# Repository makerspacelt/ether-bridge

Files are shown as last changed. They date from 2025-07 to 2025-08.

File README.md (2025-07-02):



---
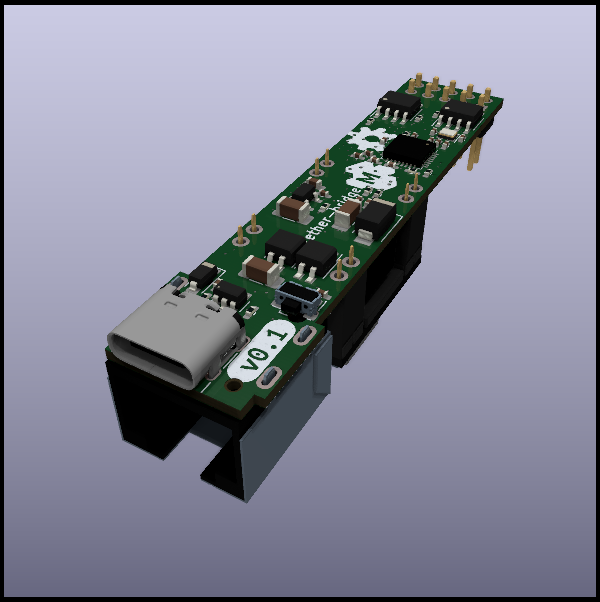
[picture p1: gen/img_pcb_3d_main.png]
PCB 3d main


Ether-bridge

NOTE: This is only a prototype now, so things might not work, and everything might change 

This hardware is meant as an Ethernet upgrade for devices that only support
I2C/UART/RS485/CAN communications. This should be used with a device-specific
firmware that exposes SCPI commands for all functions of a particular device.

Basic target features:

* Ethernet connection
* PoE .af 12w
* CAN
* RS-485
* i2c/UART
* 1x GPIO
* LXI/SCPI support via raw TCP
* Compatibility with ESPHome and Home Assistant

Dev NOTE: before commit, run `./kibot.sh` to regenerate documentation, bom, gerbers and other assets.

* [schematics.pdf](gen/schematics.pdf)
* [pcb.pdf with dimensions](gen/pcb.pdf)
* [ibom.html](gen/single/ibom.html)

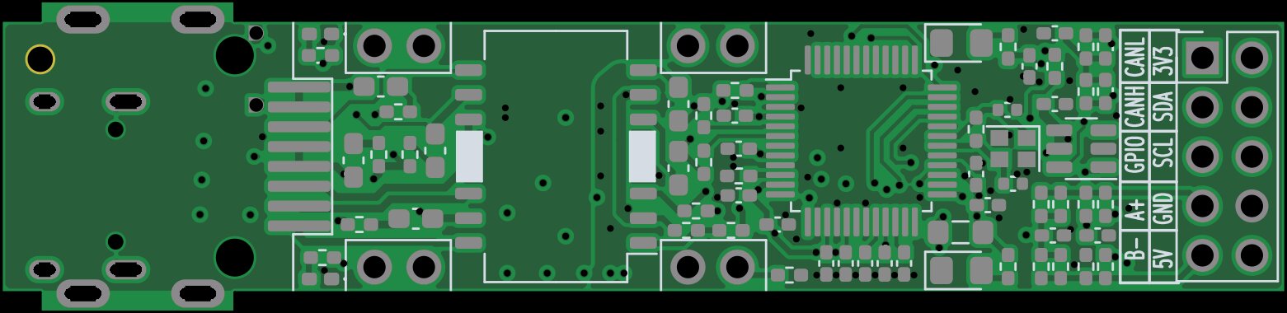
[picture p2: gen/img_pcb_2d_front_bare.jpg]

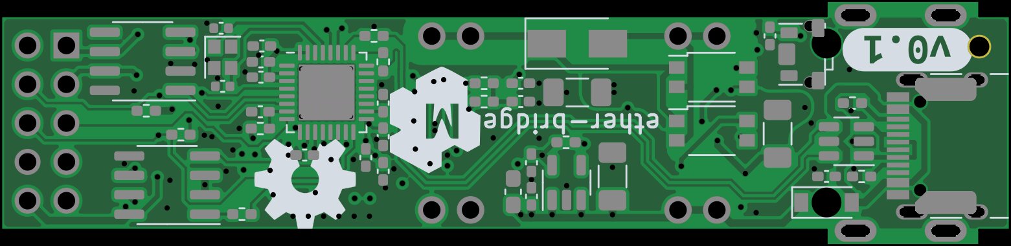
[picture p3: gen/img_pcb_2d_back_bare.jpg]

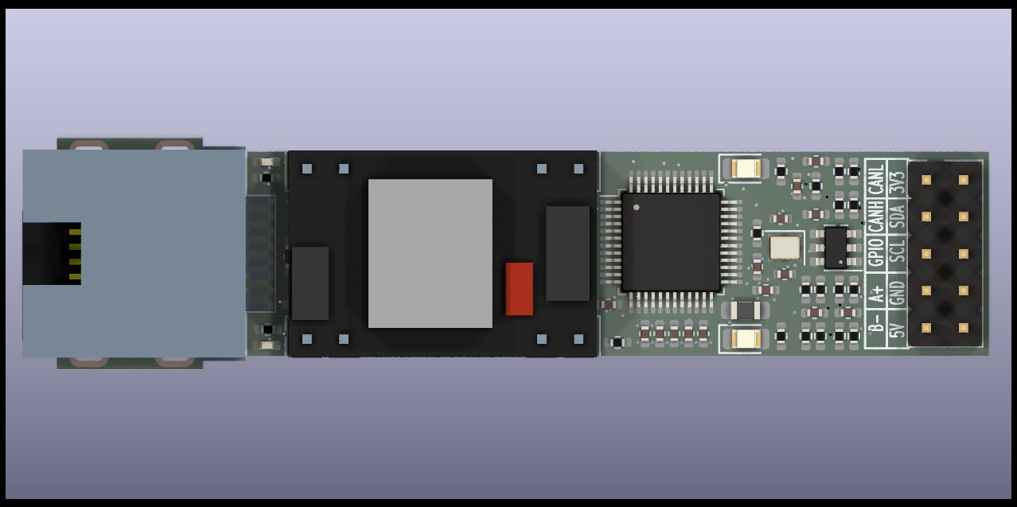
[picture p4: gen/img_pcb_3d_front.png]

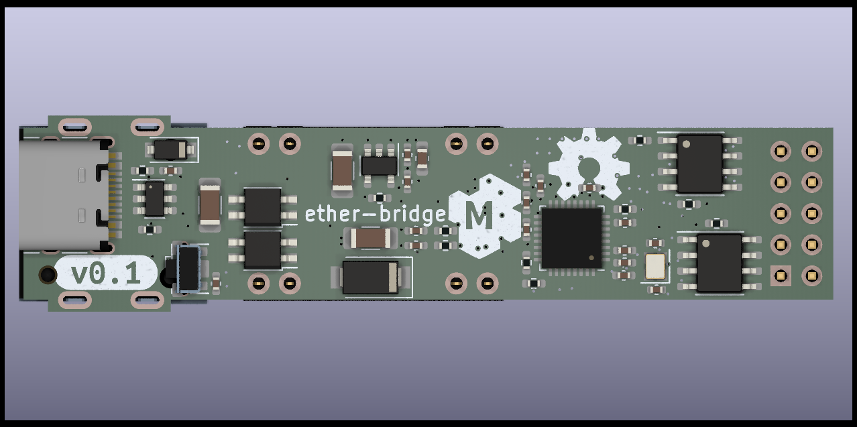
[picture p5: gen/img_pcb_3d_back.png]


---

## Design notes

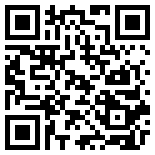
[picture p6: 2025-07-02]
gen/qr_link.png

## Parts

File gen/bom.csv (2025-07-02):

Row | Description | Part | References | Value | Footprint | Quantity Per PCB | Status | Datasheet | jlc-part-type | lcsc#
1 | Unpolarized capacitor | C | C31,C32,C33,C34 | 10p | C_0402_1005Metric | 4 |  | ~ | ??? | C1634
2 | Unpolarized capacitor | C | C17,C18 | 6n8 | C_0603_1608Metric_Pad1.08x0.95mm_HandSolder | 2 |  | ~ | B+ | C1631
3 | Unpolarized capacitor | C | C1,C2,C3,C4,C5,C8,C16,C19,C21,C22,C23,C25,C26,C27,C28,C29,C35,C36,C37,C41,C42,C43,C44,C45 | 100n | C_0402_1005Metric_Pad0.74x0.62mm_HandSolder | 24 |  | ~ | B+ | C1525
4 | Unpolarized capacitor | C | C40 | 1u | C_0402_1005Metric_Pad0.74x0.62mm_HandSolder | 1 |  | ~ | B+ | C52923
5 | Unpolarized capacitor | C | C24 | 4u7 | C_0402_1005Metric_Pad0.74x0.62mm_HandSolder | 1 |  | ~ | B+ | C23733
6 | Unpolarized capacitor | C | C6 | 100u/10v | C_1206_3216Metric_Pad1.33x1.80mm_HandSolder | 1 |  | ~ | E+ | C312983
7 | Unpolarized capacitor | C | C7 | 10u/10v | C_0603_1608Metric_Pad1.08x0.95mm_HandSolder | 1 |  | ~ | B+ | C19702
8 | Unpolarized capacitor | C | C9,C20,C30,C38,C39 | 10u/6v3 | C_0402_1005Metric_Pad0.74x0.62mm_HandSolder | 5 |  | ~ | B+ | C15525
9 | Unpolarized capacitor | C | C13 | 1n/2kv | C_1206_3216Metric_Pad1.33x1.80mm_HandSolder | 1 |  | ~ | B+ | C9196
10 | Unpolarized capacitor | C | C10,C11,C12,C15 | 22n/100v | C_0603_1608Metric_Pad1.08x0.95mm_HandSolder | 4 |  | ~ | E+ | C22374871
11 | Unpolarized capacitor | C | C14 | 4n7/2kv | C_1206_3216Metric_Pad1.33x1.80mm_HandSolder | 1 |  | ~ | E+ | C41017
12 | Schottky diode | D_Schottky | D8 | B5819W | D_SOD-123 | 1 |  | https://www.lcsc.com/datasheet/lcsc_datasheet_2304140030_Jiangsu-Changjing-Electronics-Technology-Co---Ltd--B5819W-SL_C8598.pdf | B+ | C8598
13 | Diode bridge, +ve/-ve/AC/AC | D_Bridge_+-AA | D3,D4 | D_Bridge_+-AA | Diode_Bridge_Diotec_MicroDil_3.0x3.0x1.8mm | 2 |  | https://lcsc.com/datasheet/lcsc_datasheet_2410122110_-DIOTEC-MYS250_C3589227.pdf | E+ | C3589227
14 | Light emitting diode | LED | D1,D2 | GREEN | LED_0805_2012Metric_Pad1.15x1.40mm_HandSolder | 2 |  | https://lcsc.com/datasheet/lcsc_datasheet_1806151820_Hubei-KENTO-Elec-KT-0805G_C2297.pdf | B+ | C2297
15 | Light emitting diode | LED | D6,D7 | GREEN | LED_0402_1005Metric_Pad0.77x0.64mm_HandSolder | 2 |  | https://lcsc.com/datasheet/lcsc_datasheet_2504101957_XINGLIGHT-XL-1005UGC_C965793.pdf | E+ | C965793
16 | Zener diode | D_Zener | D5 | SMAJ58A | D_SMA | 1 |  | https://lcsc.com/datasheet/lcsc_datasheet_2504211430_GOODWORK-SMAJ58A_C2980408.pdf | E+ | C2980408
17 | Ferrite bead, small symbol | FerriteBead_Small | FB1 | 600R@100MHz | L_0805_2012Metric_Pad1.05x1.20mm_HandSolder | 1 |  | ~ | B+ | C1017
18 | Generic connector, double row, 02x05, odd/even pin numbering scheme (row 1 odd numbers, row 2 even numbers), script generated (kicad-library-utils/schlib/autogen/connector/) | Conn_02x05_Odd_Even | J1 | 2x5 | PinHeader_2x05_P2.54mm_Vertical | 1 |  | ~ | -
19 | RJ connector, 8P8C (8 positions 8 connected), Shielded | RJ45_Shielded | J2 | RJ45_Shielded | RJ45_FG_RJ-064-1 | 1 |  | https://lcsc.com/datasheet/lcsc_datasheet_2306211558_FG-RJ-064-1_C7205199.pdf | E+ | C7205199
20 | USB 2.0-only Type-C Receptacle connector | USB_C_Receptacle_USB2.0 | J3 | USB_C_Receptacle_USB2.0 | USB_C_Receptacle_HRO_TYPE-C-31-M-12 | 1 |  | https://lcsc.com/datasheet/lcsc_datasheet_2410010003_Korean-Hroparts-Elec-TYPE-C-31-M-12_C165948.pdf | E+ | C165948
21 | Resistor | R | R5,R6 | 10R | R_0402_1005Metric_Pad0.72x0.64mm_HandSolder | 2 |  | ~ | B+ | C25077
22 | Resistor | R | R40,R41 | 22R | R_0402_1005Metric_Pad0.72x0.64mm_HandSolder | 2 |  | ~ | B+ | C25092
23 | Resistor | R | R29,R30,R31,R32 | 33R | R_0402_1005Metric_Pad0.72x0.64mm_HandSolder | 4 |  | ~ | B+ | C25105
24 | Resistor | R | R22,R23,R24,R25 | 49R9 | R_0402_1005Metric_Pad0.72x0.64mm_HandSolder | 4 |  | ~ | B+ | C25120
25 | Resistor | R | R18,R19,R20,R21 | 75R | R_0402_1005Metric_Pad0.72x0.64mm_HandSolder | 4 |  | ~ | ER+ | C25133
26 | Resistor | R | R7,R8,R11,R12,R13,R14,R15,R16 | 120R | R_0402_1005Metric_Pad0.72x0.64mm_HandSolder | 8 |  | ~ | B+ | C25079
27 | Resistor | R | R2,R3,R4,R26,R27,R34,R35,R36,R37,R38,R39 | 4k7 | R_0402_1005Metric_Pad0.72x0.64mm_HandSolder | 11 |  | ~ | B+ | C25900
28 | Resistor | R | R1,R9,R10 | 10k | R_0402_1005Metric_Pad0.72x0.64mm_HandSolder | 3 |  | ~ | B+ | C25744
29 | Resistor | R | R28 | 12k4 | R_0402_1005Metric_Pad0.72x0.64mm_HandSolder | 1 |  | ~ | E+ | C11692
30 | Resistor | R | R17 | 470k | R_0402_1005Metric_Pad0.72x0.64mm_HandSolder | 1 |  | ~ | ER+ | C25790
31 | Resistor | R | R33 | 1M | R_0402_1005Metric_Pad0.72x0.64mm_HandSolder | 1 |  | ~ | B+ | C26083
32 | Push button switch, generic, two pins | SW_Push_MountingPin | SW1 | MOD | tiny-btn | 1 |  | https://lcsc.com/datasheet/lcsc_datasheet_2410121643_ALPSALPINE-SKTDLHE010_C380198.pdf | E+ | C380198
33 | Ethernet LAN 10/100 Base-Tx Transformer CT, SMD | Wuerth_749013011A | TR1 | CND-tek-H1102N | Transformer_Ethernet_SO-16_7.11x12.7mm | 1 |  | https://lcsc.com/datasheet/lcsc_datasheet_2412231915_CND-tek-H1102N_C42418465.pdf | E+ | C42418465
34 |  | DP9900 | U4 | DP9900 | PSU_DP9900LP | 1 |  | https://lcsc.com/datasheet/lcsc_datasheet_2410122022_SDAPO-DP9900LP-5V_C5380108.pdf | E+ | C5380108
35 | Digital Temperature Sensor with I2C/SMBus Interface, +/-2° C, one-shot conversion, alert, SOT-23-6 | TMP101 | U1 | GX101 | SOT-23-6 | 1 |  | https://www.lcsc.com/datasheet/lcsc_datasheet_2409280202_GXCAS-GX101S_C5441728.pdf | E+ | C5441728
36 | Half duplex RS-485/RS-422, 0.25 Mbps, ±15kV electro-static discharge (ESD) protection, with slew-rate, with low-power shutdown, with receiver/driver enable, 128 receiver drive kapacitity, DIP-8 and SOIC-8 | MAX487E | U2 | MAX13487E | SOIC-8_3.9x4.9mm_P1.27mm | 1 |  | https://lcsc.com/datasheet/lcsc_datasheet_2410121837_Analog-Devices-Inc--Maxim-Integrated-MAX13487EESA-T_C18347.pdf | E+ | C18347
37 | 150mA, Tiny CMOS LDO With Shutdown, Fixed Voltage, SOT-23-5 | MCP1802x-xx02xOT | U5 | ME6211C33 | SOT-23-5 | 1 |  | https://lcsc.com/datasheet/lcsc_datasheet_1811131510_MICRONE-Nanjing-Micro-One-Elec-ME6211C33M5G-N_C82942.pdf | E+ | C82942
38 | Very low capacitance ESD protection diode, 2 data-line, SOT-23-6 | USBLC6-2SC6 | U7 | USBLC6-2SC6 | SOT-23-6 | 1 |  | https://www.lcsc.com/datasheet/lcsc_datasheet_2311091738_UMW-Youtai-Semiconductor-Co---Ltd--USBLC6-2SC6_C2687116.pdf | E+ | C2687116
39 | 10/100Mb SPI Ethernet controller with TCP/IP stack, LQFP-48 | W5500 | U6 | W5500 | LQFP-48_7x7mm_P0.5mm | 1 |  | https://lcsc.com/datasheet/lcsc_datasheet_2410121618_WIZNET-W5500_C32843.pdf | E+ | C32843
40 | High-Speed CAN Transceiver, standby mode, split pin, SOIC-8 | TJA1042T | U3 | XL1050 | SOIC-8_3.9x4.9mm_P1.27mm | 1 |  | https://www.lcsc.com/datasheet/lcsc_datasheet_2309141025_XINLUDA-XL1050_C609746.pdf | E+ | C609746
41 | esp32-C3FH4X 4MB flash QFN32-1EP 5x5mm EP3.7x3.7mm | esp32-C3FH4X | U8 | esp32-C3FH4X | QFN-32-1EP_5x5mm_P0.5mm_EP3.65x3.65mm | 1 |  | https://www.espressif.com/sites/default/files/documentation/esp32-c3_datasheet_en.pdf | E+ | C2858491
42 | Four pin crystal, GND on pins 2 and 4 | Crystal_GND24 | Y1 | 25MHz | Crystal_SMD_2016-4Pin_2.0x1.6mm | 1 |  | https://lcsc.com/datasheet/lcsc_datasheet_2504101957_Shenzhen-SCTF-Elec-SX1B25-000F0810F30_C7301943.pdf | E+ | C7301943
43 | Four pin crystal, GND on pins 2 and 4 | Crystal_GND24 | Y2 | 40MHz | Crystal_SMD_2016-4Pin_2.0x1.6mm | 1 |  | https://lcsc.com/datasheet/lcsc_datasheet_2409272203_Yajingxin-T201640MFBDE2X_C20885029.pdf | E+ | C20885029

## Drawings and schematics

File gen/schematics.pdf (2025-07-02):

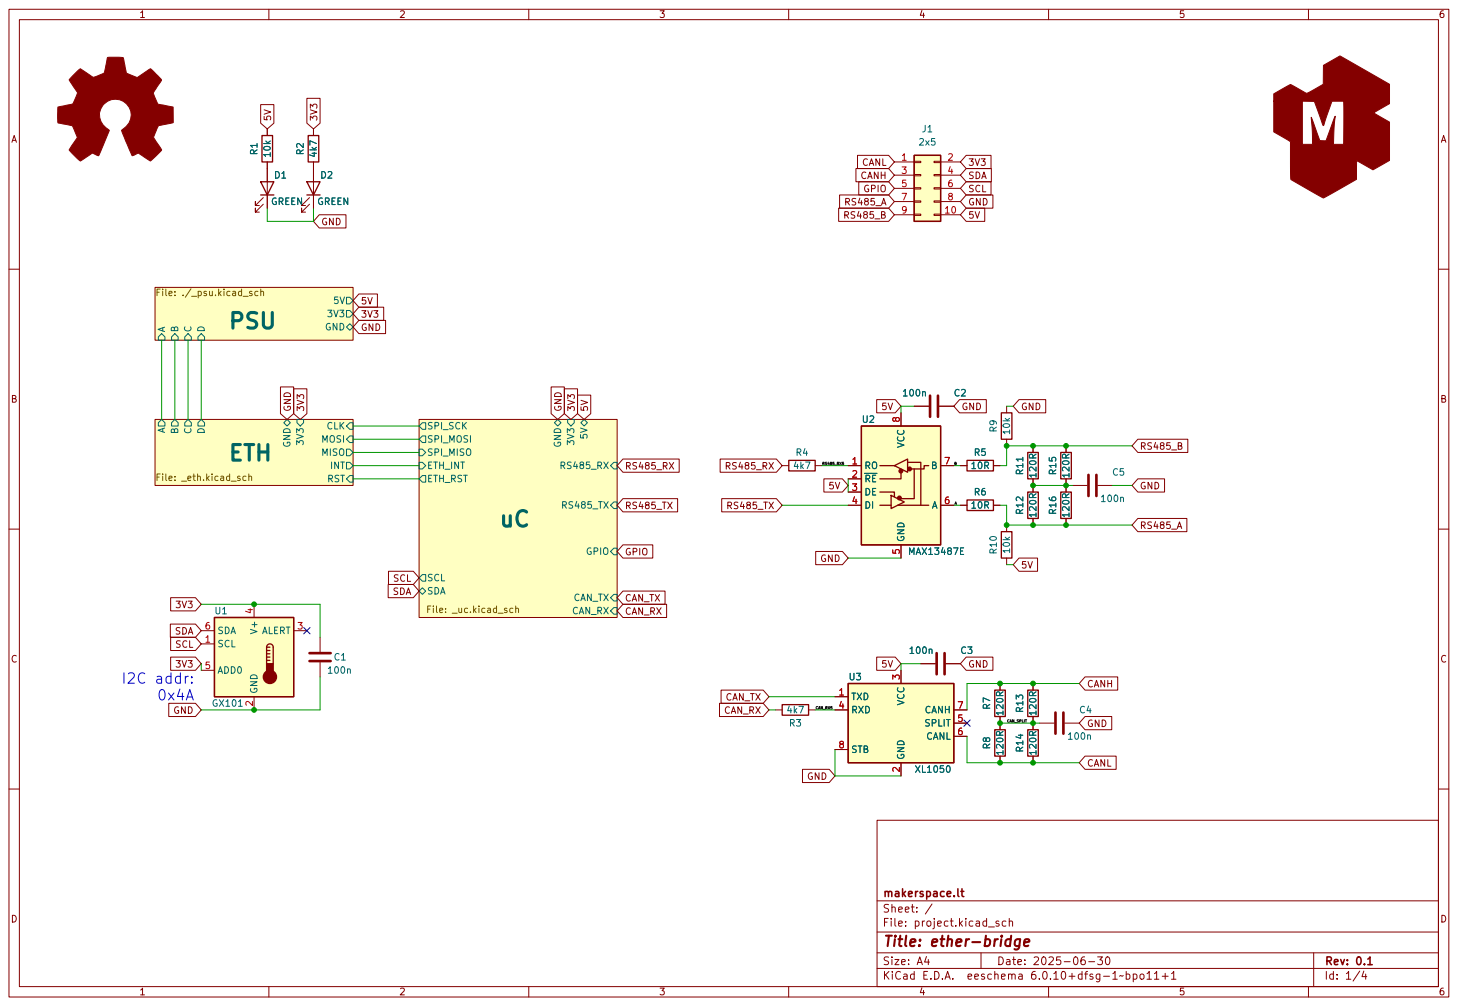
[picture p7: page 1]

3V3 SCL SDA CANL GPIO
RS485_A CANH

File: project.kicad_sch Sheet: / makerspace.lt 3V3 GND

3 RXD 4 SPLIT 5 CANL 6 CANH 7 STB 8 R16 120R R15 R11 120R 120R R12 120R

3 RXD 4 SPLIT 5 CANL 6 CANH 7 STB 8 U3 XL1050

Id: 1/4 Title: ether-bridge

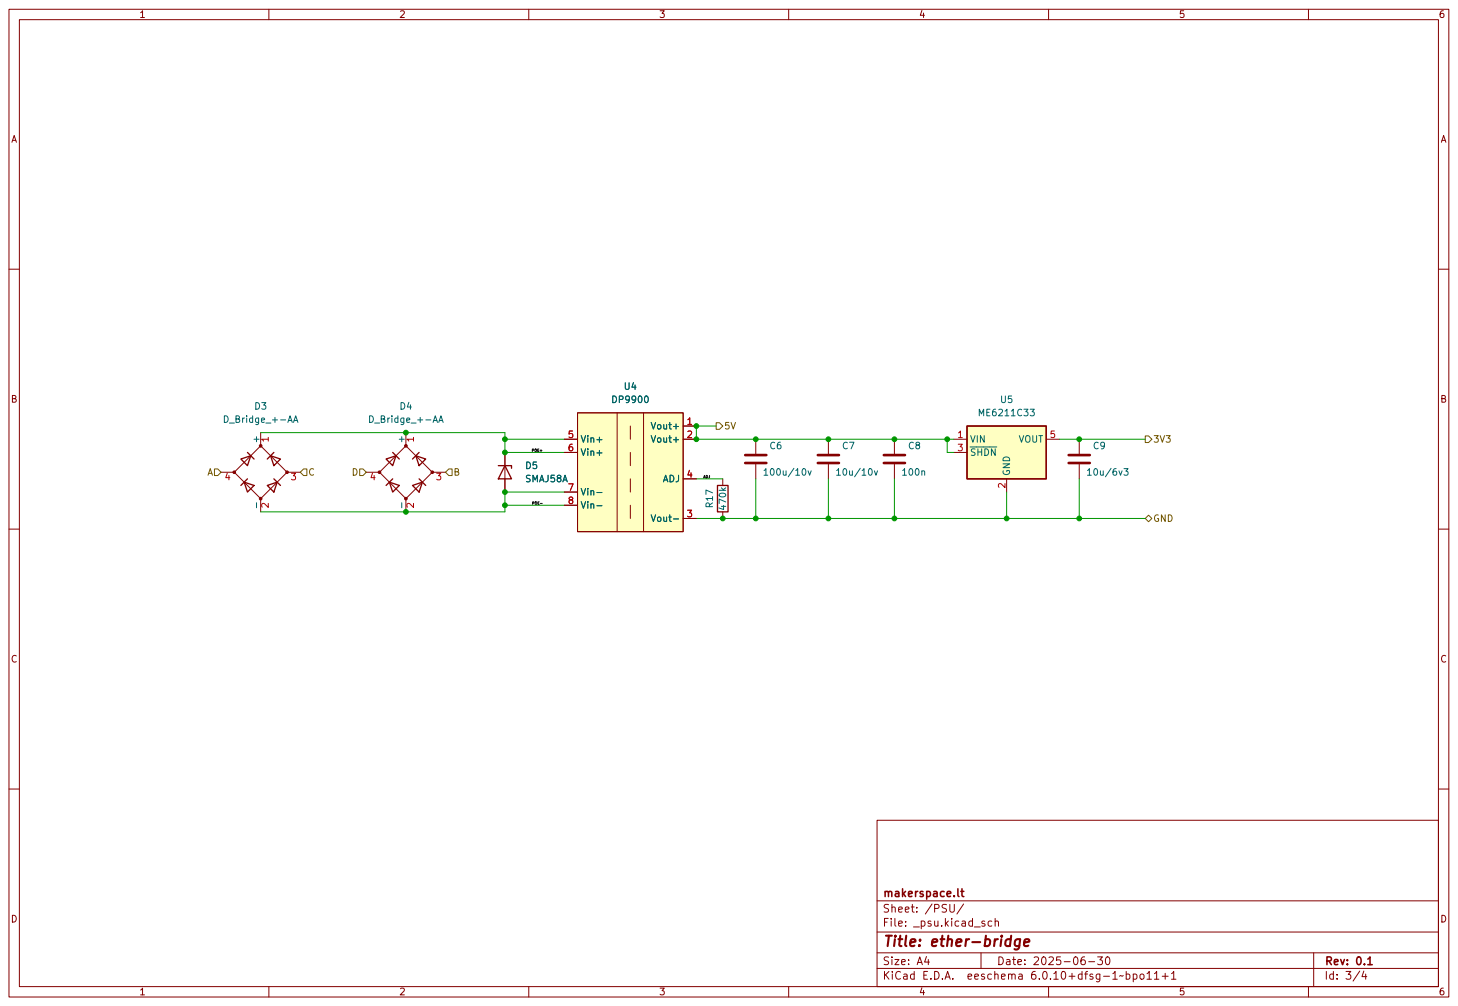
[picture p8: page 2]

Id: 3/4 Title: ether-bridge

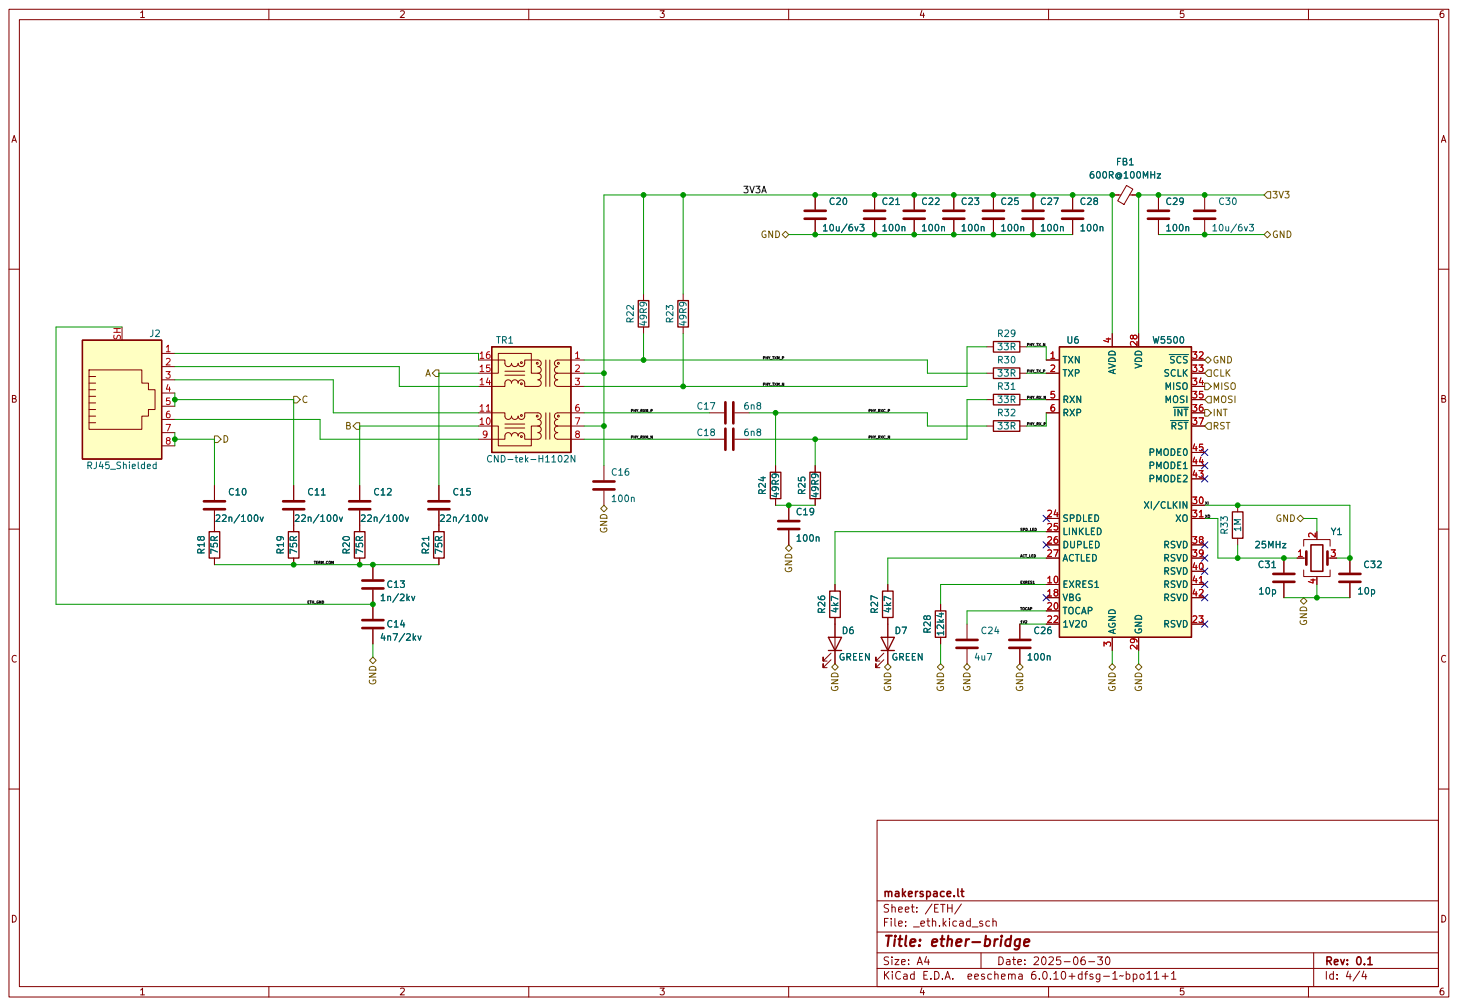
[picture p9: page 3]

4 RSVD 40 RSVD 41 RSVD 42 PMODE2 43 PMODE1 44 PMODE0 45 RXN 5 RXP 6 U6 W5500 C32

4 RSVD 40 RSVD 41 RSVD 42 PMODE2 43 PMODE1 44 PMODE0 45 RXN 5 RXP 6 Y1

3 XI/CLKIN 30 XO 31 ~{SCS}32 SCLK 33 MISO 34 MOSI 35 ~{INT}36 ~{RST}37 RSVD 38 RSVD 39 AVDD

File: _eth.kicad_sch Sheet: /ETH/ makerspace.lt

Id: 4/4 Title: ether-bridge

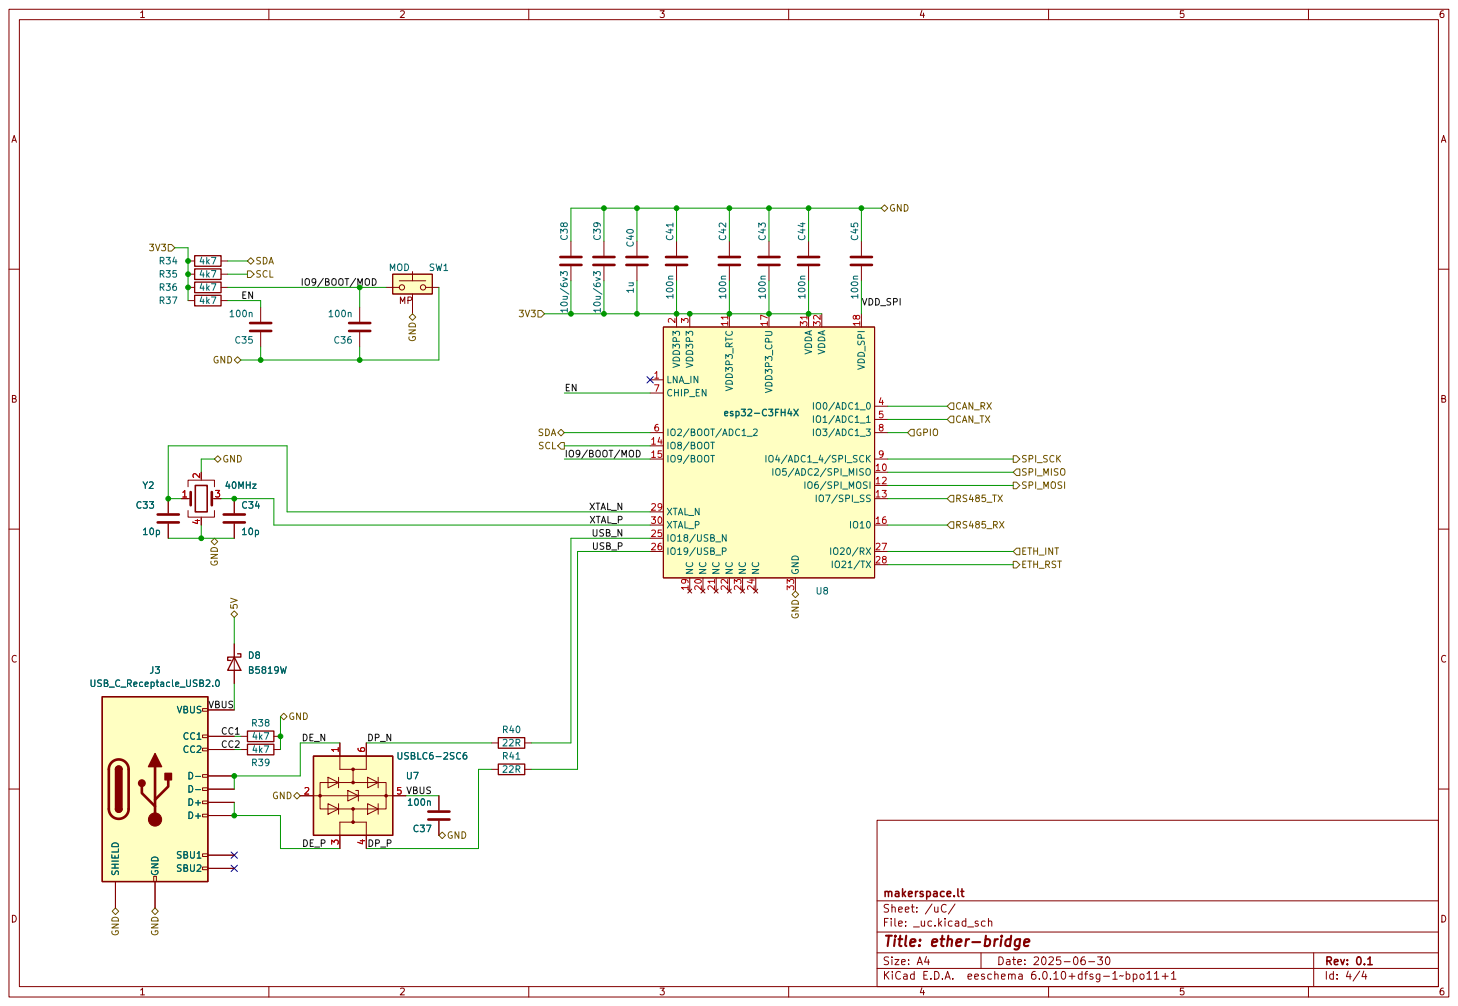
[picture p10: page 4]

File: _uc.kicad_sch Sheet: /uC/ makerspace.lt

Id: 4/4 Title: ether-bridge

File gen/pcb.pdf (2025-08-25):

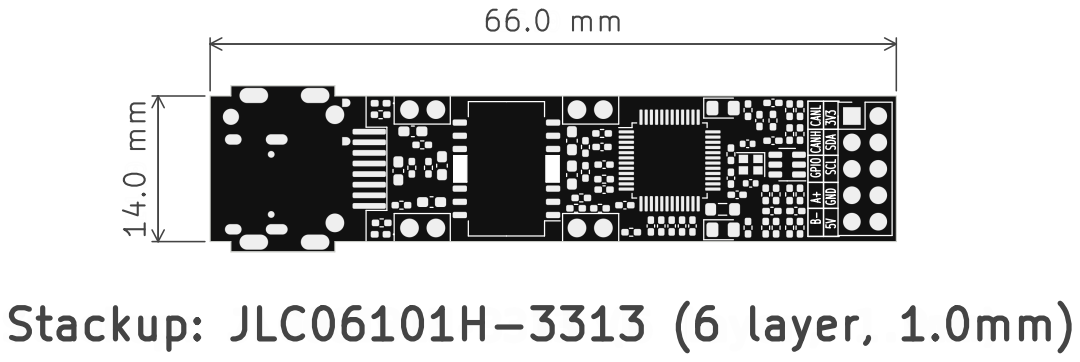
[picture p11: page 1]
Stackup: JLC06101H-3313 (6 layer,

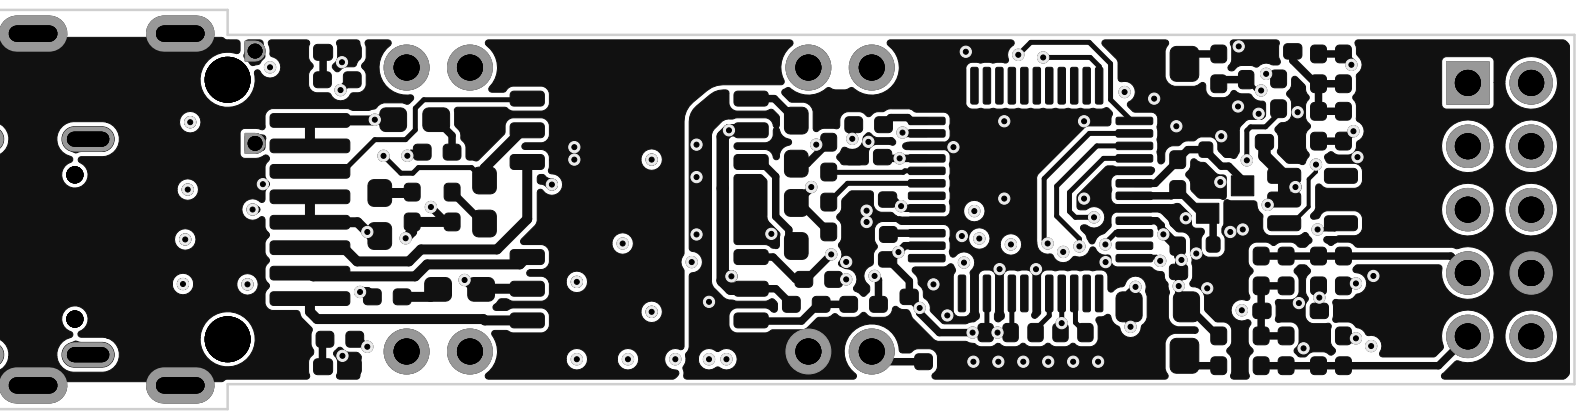
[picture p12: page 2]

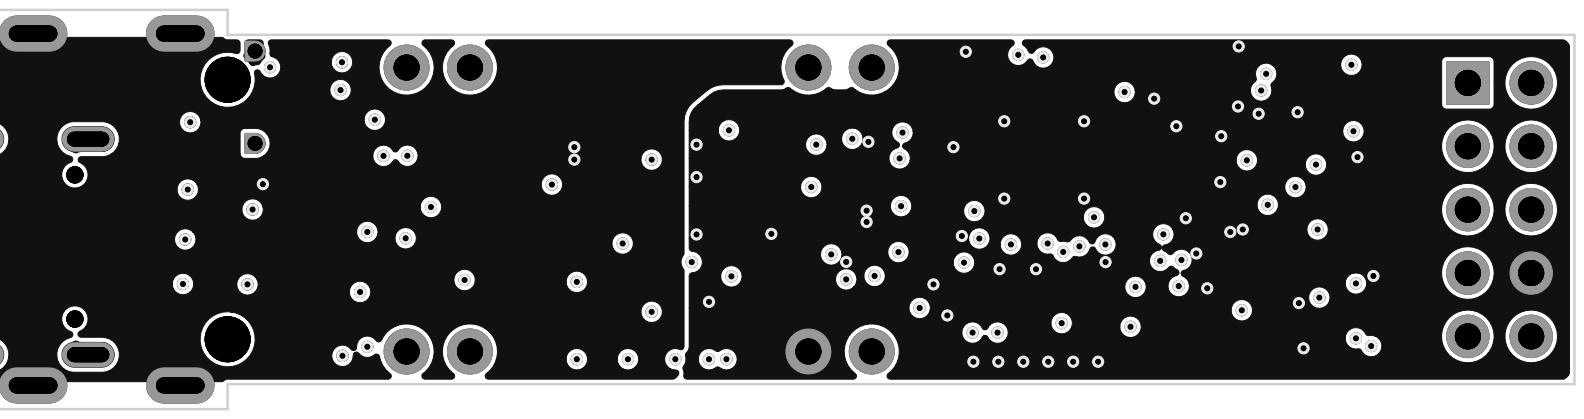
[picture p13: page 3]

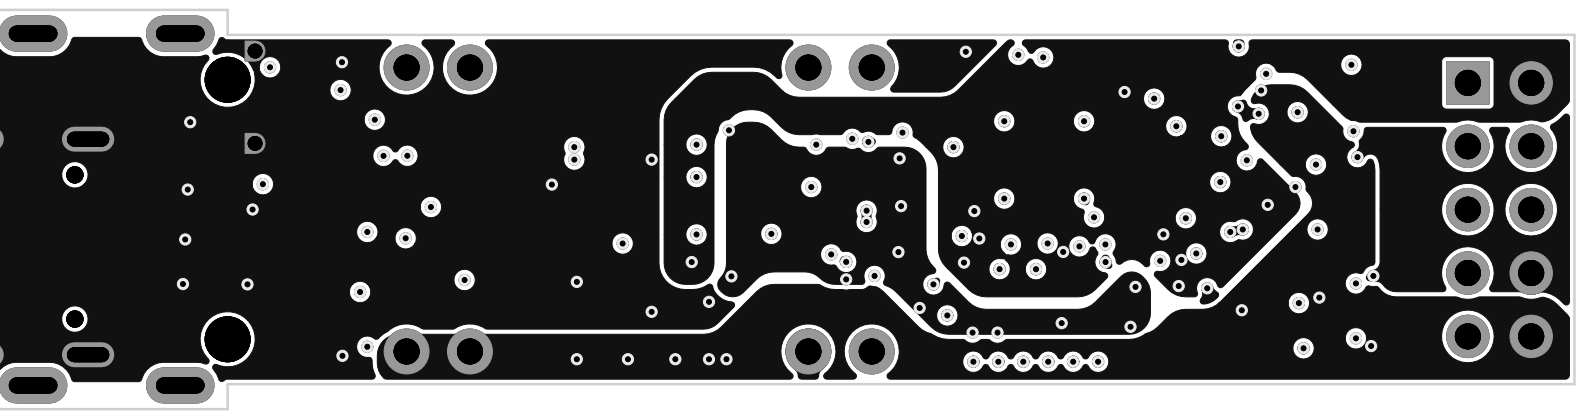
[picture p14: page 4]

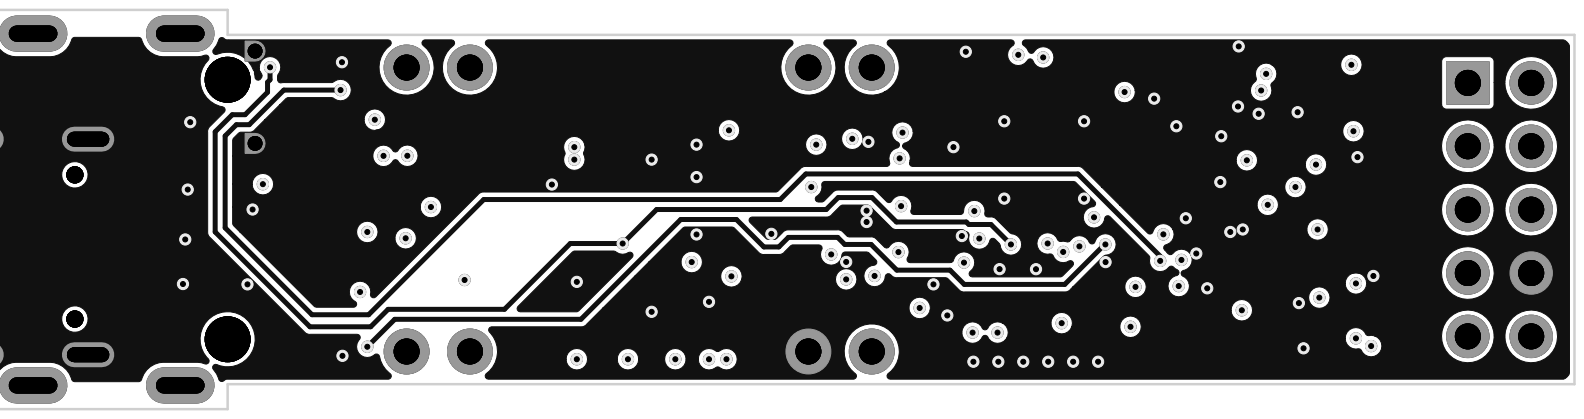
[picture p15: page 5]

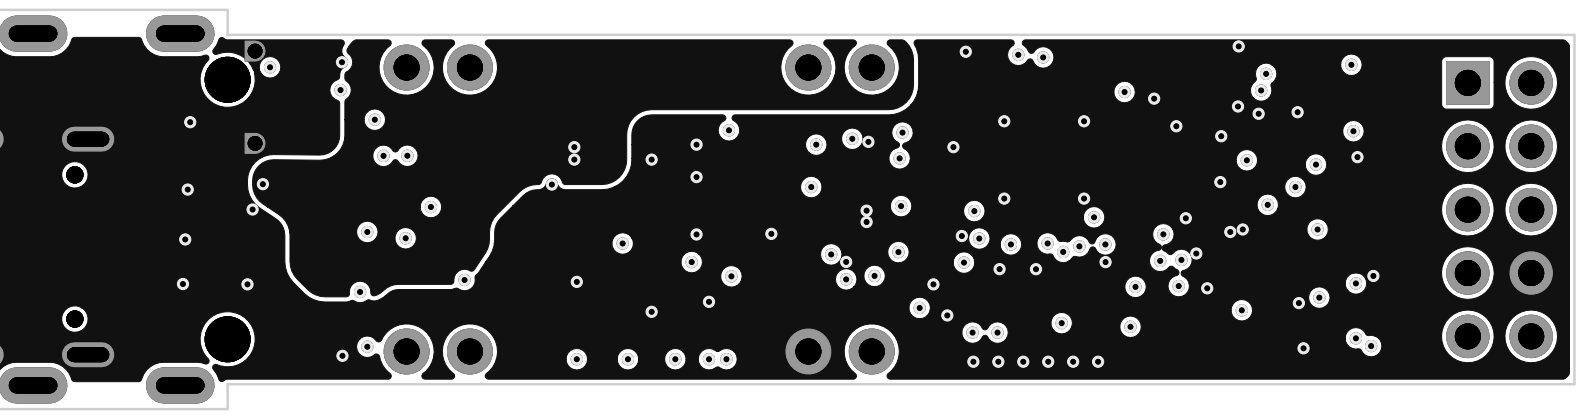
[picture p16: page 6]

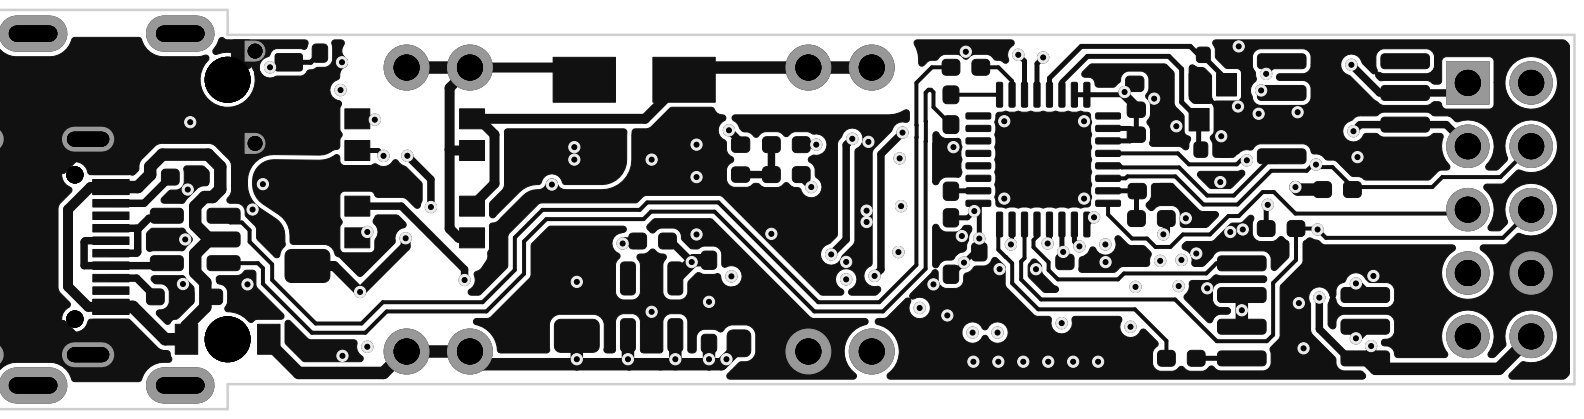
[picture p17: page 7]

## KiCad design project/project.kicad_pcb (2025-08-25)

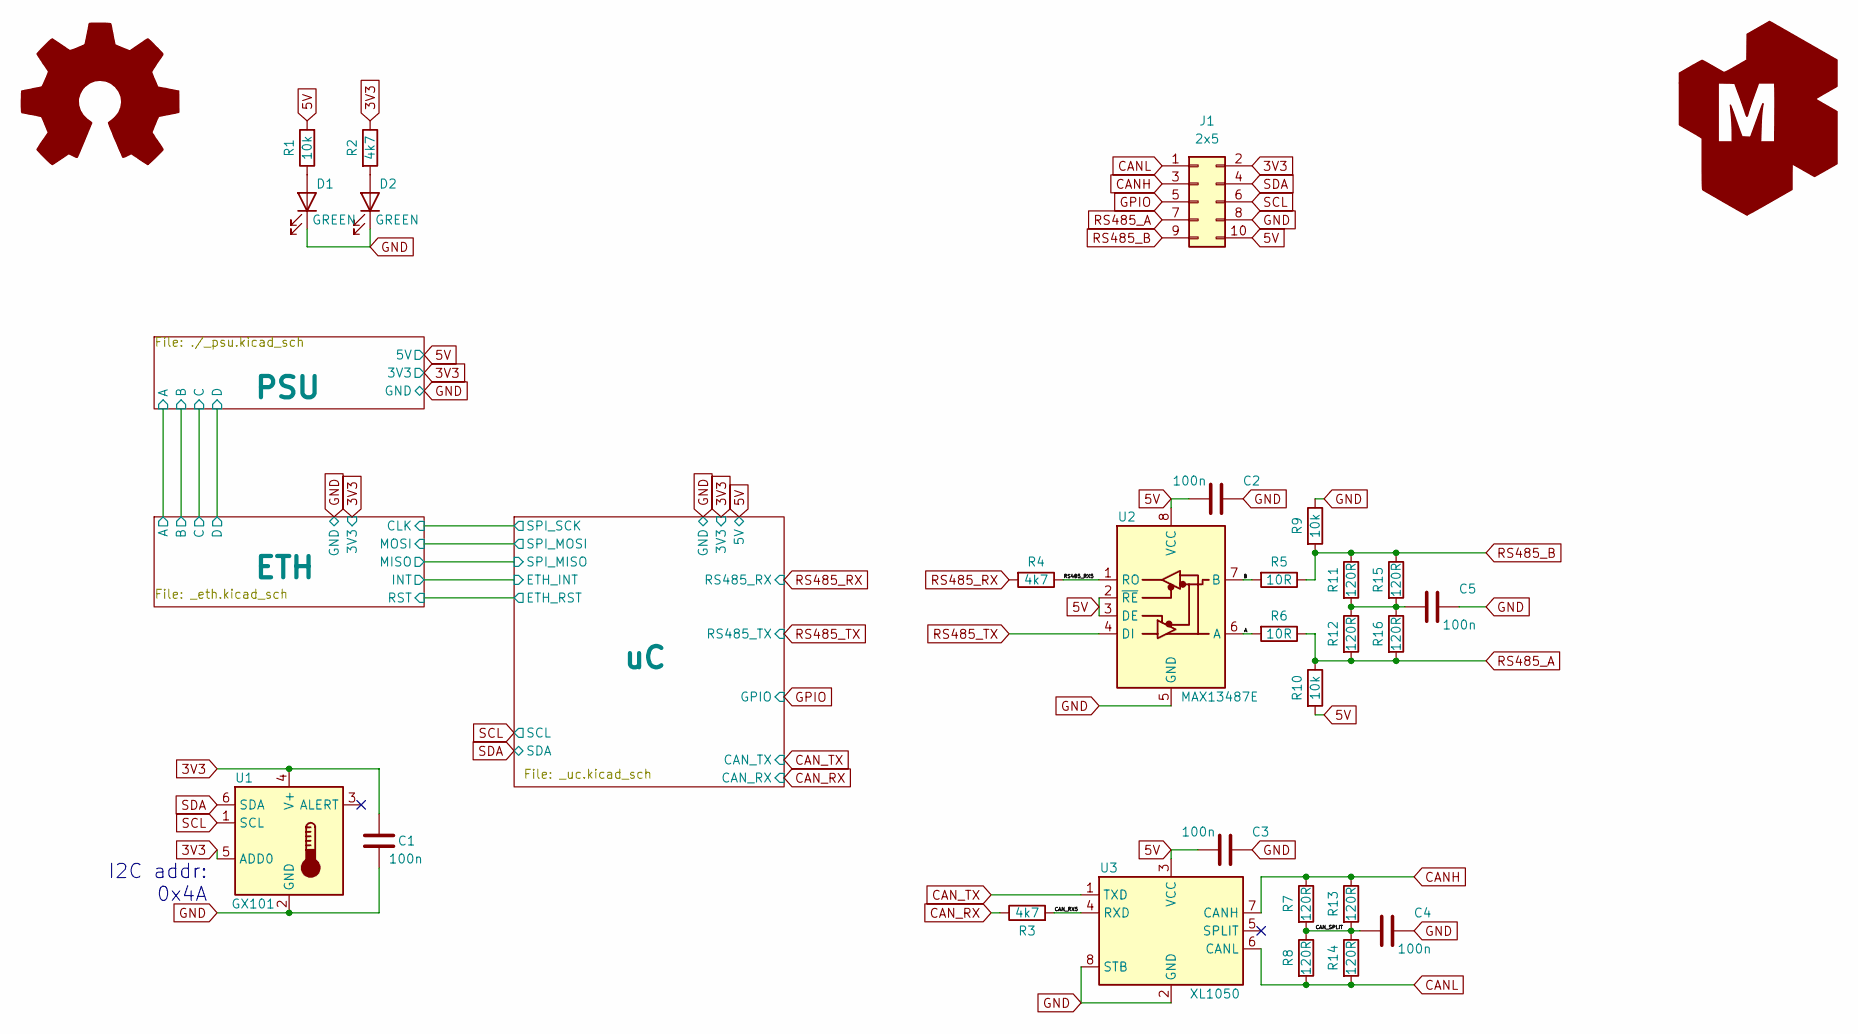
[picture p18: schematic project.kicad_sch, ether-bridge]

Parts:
C1, C2, C3, C4, C5: 100n; C_0402_1005Metric_Pad0.74x0.62mm_HandSolder; jlc-part-type B+
D1, D2: GREEN; LED_0805_2012Metric_Pad1.15x1.40mm_HandSolder; jlc-part-type B+
G1: Logo_Open_Hardware_Large; OSHW-Symbol_6.7x6mm_SilkScreen
G2: LOGO_KMS; logo_kms_small_silkscreen
J1: 2x5; PinHeader_2x05_P2.54mm_Vertical
R1, R9, R10: 10k; R_0402_1005Metric_Pad0.72x0.64mm_HandSolder; jlc-part-type B+
R2, R3, R4: 4k7; R_0402_1005Metric_Pad0.72x0.64mm_HandSolder; jlc-part-type B+
R5, R6: 10R; R_0402_1005Metric_Pad0.72x0.64mm_HandSolder; jlc-part-type B+
R7, R8, R11, R12, R13, R14, R15, R16: 120R; R_0402_1005Metric_Pad0.72x0.64mm_HandSolder; jlc-part-type B+
U1: GX101; SOT-23-6; jlc-part-type E+
U2: MAX13487E; SOIC-8_3.9x4.9mm_P1.27mm; jlc-part-type E+
U3: XL1050; SOIC-8_3.9x4.9mm_P1.27mm; jlc-part-type E+

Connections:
3V3: C1.1, J1.2, R2.1, U1.4 (V+), U1.5 (ADD0); also elsewhere on the board
5V: C2.1, C3.1, J1.10, R1.2, R10.2, U2.2 (~RE), U2.3 (DE), U2.8 (VCC), U3.3 (VCC); also elsewhere on the board
/A: R6.2, U2.6 (A)
/B: R5.2, U2.7 (B)
/CAN_RX5: R3.2, U3.4 (RXD)
/CAN_SPLIT: C4.1, R7.2, R8.1, R13.2, R14.1
/RS485_RX5: R4.1, U2.1 (RO)
CANH: J1.3, R7.1, R13.1, U3.7 (CANH)
CANL: J1.1, R8.2, R14.2, U3.6 (CANL)
CAN_RX: R3.1; also elsewhere on the board
CAN_TX: U3.1 (TXD); also elsewhere on the board
GND: C1.2, C2.2, C3.2, C4.2, C5.2, D1.1 (K), D2.1 (K), J1.8, R9.1, U1.2 (GND), U2.5 (GND), U3.2 (GND), U3.8 (STB); also elsewhere on the board
GPIO: J1.5; also elsewhere on the board
unnamed: C5.1, R11.2, R12.1, R15.2, R16.1
unnamed: D1.2 (A), R1.1
unnamed: D2.2 (A), R2.2
RS485_A: J1.7, R6.1, R10.1, R12.2, R16.2
RS485_B: J1.9, R5.1, R9.2, R11.1, R15.1
RS485_RX: R4.2; also elsewhere on the board
RS485_TX: U2.4 (DI); also elsewhere on the board
SCL: J1.6, U1.1 (SCL); also elsewhere on the board
SDA: J1.4, U1.6 (SDA); also elsewhere on the board

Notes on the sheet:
I2C addr: 0x4A

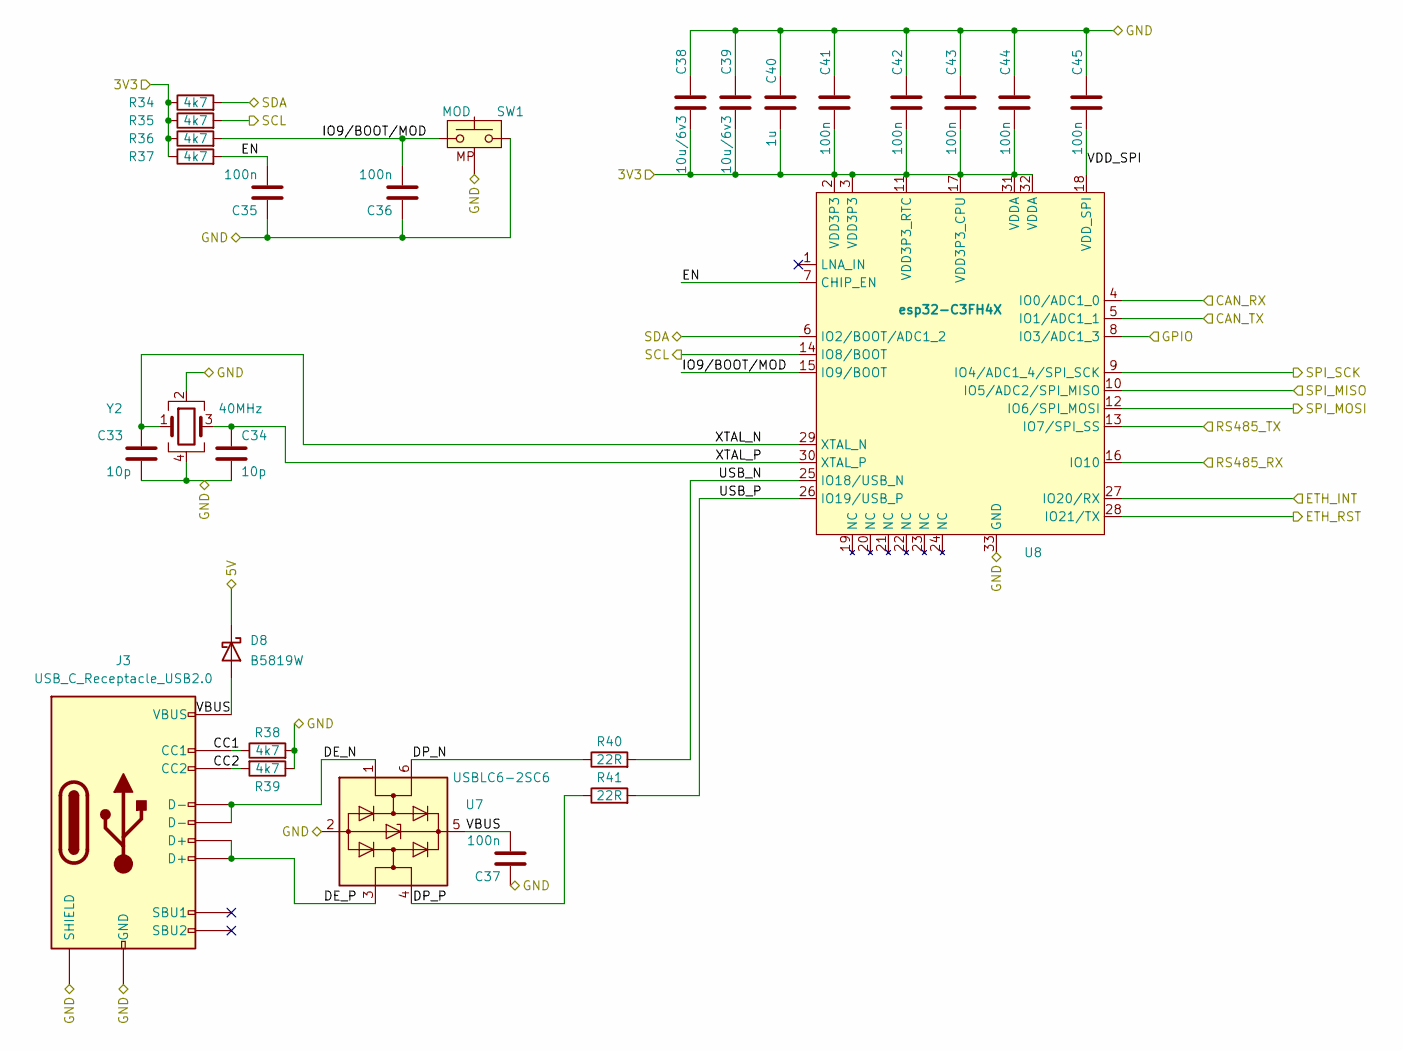
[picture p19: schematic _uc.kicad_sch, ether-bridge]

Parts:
C33, C34: 10p; C_0402_1005Metric; jlc-part-type ???
C35, C36, C37, C41, C42, C43, C44, C45: 100n; C_0402_1005Metric_Pad0.74x0.62mm_HandSolder; jlc-part-type B+
C38, C39: 10u/6v3; C_0402_1005Metric_Pad0.74x0.62mm_HandSolder; jlc-part-type B+
C40: 1u; C_0402_1005Metric_Pad0.74x0.62mm_HandSolder; jlc-part-type B+
D8: B5819W; D_SOD-123; jlc-part-type B+
J3: USB_C_Receptacle_USB2.0; USB_C_Receptacle_HRO_TYPE-C-31-M-12; jlc-part-type E+
R34, R35, R36, R37, R38, R39: 4k7; R_0402_1005Metric_Pad0.72x0.64mm_HandSolder; jlc-part-type B+
R40, R41: 22R; R_0402_1005Metric_Pad0.72x0.64mm_HandSolder; jlc-part-type B+
SW1: MOD; tiny-btn; jlc-part-type E+
U7: USBLC6-2SC6; SOT-23-6; jlc-part-type E+
U8: esp32-C3FH4X; QFN-32-1EP_5x5mm_P0.5mm_EP3.65x3.65mm; jlc-part-type E+
Y2: 40MHz; Crystal_SMD_2016-4Pin_2.0x1.6mm; jlc-part-type E+

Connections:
3V3: C38.2, C39.2, C40.2, C41.1, C42.1, C43.1, C44.1, R34.1, R35.1, R36.1, R37.1, U8.2 (VDD3P3), U8.3 (VDD3P3), U8.11 (VDD3P3_RTC), U8.17 (VDD3P3_CPU), U8.31 (VDDA), U8.32 (VDDA); also elsewhere on the board
5V: D8.1 (K); also elsewhere on the board
/ETH/CLK: U8.9 (IO4/ADC1_4/SPI_SCK); also elsewhere on the board
/ETH/INT: U8.27 (IO20/RX); also elsewhere on the board
/ETH/MISO: U8.10 (IO5/ADC2/SPI_MISO); also elsewhere on the board
/ETH/MOSI: U8.12 (IO6/SPI_MOSI); also elsewhere on the board
/ETH/RST: U8.28 (IO21/TX); also elsewhere on the board
/uC/CC1: J3.A5 (CC1), R38.1
/uC/CC2: J3.B5 (CC2), R39.2
/uC/DE_N: J3.A7 (D-), J3.B7 (D-), U7.1 (I/O1)
/uC/DE_P: J3.A6 (D+), J3.B6 (D+), U7.3 (I/O2)
/uC/DP_N: R40.1, U7.6 (I/O1)
/uC/DP_P: R41.1, U7.4 (I/O2)
/uC/EN: C35.2, R37.2, U8.7 (CHIP_EN)
/uC/IO9/BOOT/MOD: C36.2, R36.2, SW1.2, U8.15 (IO9/BOOT)
/uC/USB_N: R40.2, U8.25 (IO18/USB_N)
/uC/USB_P: R41.2, U8.26 (IO19/USB_P)
/uC/VBUS: C37.2, D8.2 (A), J3.A4 (VBUS), J3.A9 (VBUS), J3.B4 (VBUS), J3.B9 (VBUS), U7.5 (VBUS)
/uC/VDD_SPI: C45.1, U8.18 (VDD_SPI)
/uC/XTAL_N: C33.1, U8.29 (XTAL_N), Y2.1
/uC/XTAL_P: C34.1, U8.30 (XTAL_P), Y2.3
CAN_RX: U8.4 (IO0/ADC1_0); also elsewhere on the board
CAN_TX: U8.5 (IO1/ADC1_1); also elsewhere on the board
GND: C33.2, C34.2, C35.1, C36.1, C37.1, C38.1, C39.1, C40.1, C41.2, C42.2, C43.2, C44.2, C45.2, J3.A1 (GND), J3.A12 (GND), J3.B1 (GND), J3.B12 (GND), J3.S1 (SHIELD), R38.2, R39.1, SW1.1, SW1.MP, U7.2 (GND), U8.33 (GND), Y2.2, Y2.4; also elsewhere on the board
GPIO: U8.8 (IO3/ADC1_3); also elsewhere on the board
RS485_RX: U8.16 (IO10); also elsewhere on the board
RS485_TX: U8.13 (IO7/SPI_SS); also elsewhere on the board
SCL: R35.2, U8.14 (IO8/BOOT); also elsewhere on the board
SDA: R34.2, U8.6 (IO2/BOOT/ADC1_2); also elsewhere on the board

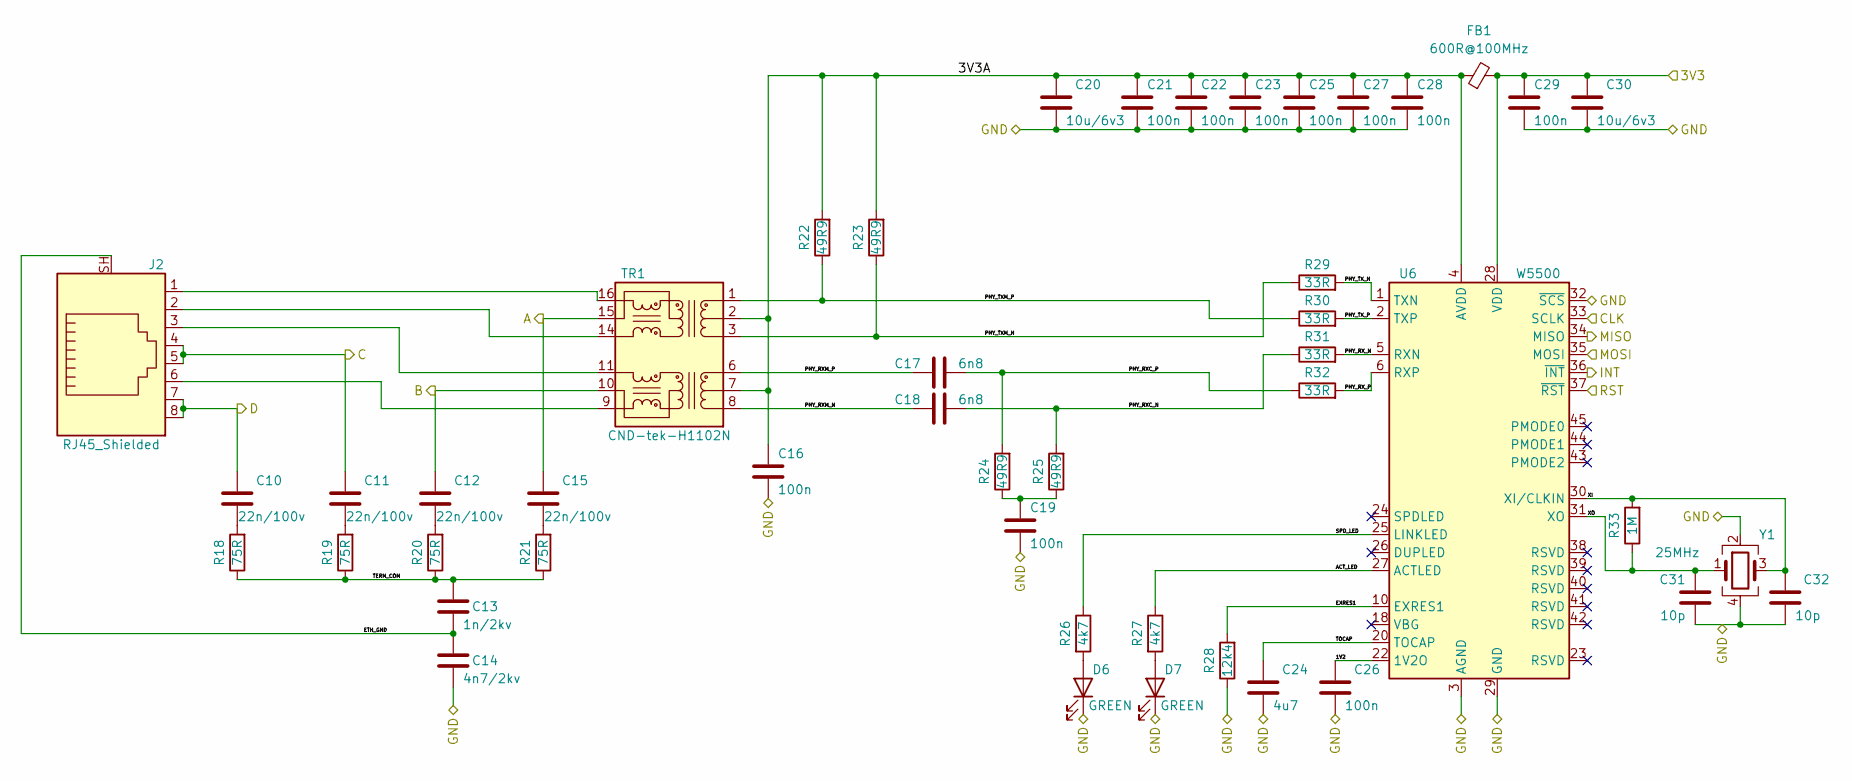
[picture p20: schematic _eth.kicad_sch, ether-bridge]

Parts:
C10, C11, C12, C15: 22n/100v; C_0603_1608Metric_Pad1.08x0.95mm_HandSolder; jlc-part-type E+
C13: 1n/2kv; C_1206_3216Metric_Pad1.33x1.80mm_HandSolder; jlc-part-type B+
C14: 4n7/2kv; C_1206_3216Metric_Pad1.33x1.80mm_HandSolder; jlc-part-type E+
C16, C19, C21, C22, C23, C25, C26, C27, C28, C29: 100n; C_0402_1005Metric_Pad0.74x0.62mm_HandSolder; jlc-part-type B+
C17, C18: 6n8; C_0603_1608Metric_Pad1.08x0.95mm_HandSolder; jlc-part-type B+
C20, C30: 10u/6v3; C_0402_1005Metric_Pad0.74x0.62mm_HandSolder; jlc-part-type B+
C24: 4u7; C_0402_1005Metric_Pad0.74x0.62mm_HandSolder; jlc-part-type B+
C31, C32: 10p; C_0402_1005Metric; jlc-part-type ???
D6, D7: GREEN; LED_0402_1005Metric_Pad0.77x0.64mm_HandSolder; jlc-part-type E+
FB1: 600R@100MHz; L_0805_2012Metric_Pad1.05x1.20mm_HandSolder; jlc-part-type B+
J2: RJ45_Shielded; RJ45_FG_RJ-064-1; jlc-part-type E+
R18, R19, R20, R21: 75R; R_0402_1005Metric_Pad0.72x0.64mm_HandSolder; jlc-part-type ER+
R22, R23, R24, R25: 49R9; R_0402_1005Metric_Pad0.72x0.64mm_HandSolder; jlc-part-type B+
R26, R27: 4k7; R_0402_1005Metric_Pad0.72x0.64mm_HandSolder; jlc-part-type B+
R28: 12k4; R_0402_1005Metric_Pad0.72x0.64mm_HandSolder; jlc-part-type E+
R29, R30, R31, R32: 33R; R_0402_1005Metric_Pad0.72x0.64mm_HandSolder; jlc-part-type B+
R33: 1M; R_0402_1005Metric_Pad0.72x0.64mm_HandSolder; jlc-part-type B+
TR1: CND-tek-H1102N; Transformer_Ethernet_SO-16_7.11x12.7mm; jlc-part-type E+
U6: W5500; LQFP-48_7x7mm_P0.5mm; jlc-part-type E+
Y1: 25MHz; Crystal_SMD_2016-4Pin_2.0x1.6mm; jlc-part-type E+

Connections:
3V3: C29.1, C30.1, FB1.2, U6.28 (VDD); also elsewhere on the board
/ETH/1V2: C26.1, U6.22 (1V2O)
/ETH/3V3A: C16.1, C20.1, C21.1, C22.1, C23.1, C25.1, C27.1, C28.1, FB1.1, R22.2, R23.2, TR1.2 (C_TD), TR1.7 (C_RD), U6.4 (AVDD), U6.8 (AVDD), U6.11 (AVDD), U6.15 (AVDD), U6.17 (AVDD), U6.21 (AVDD)
/ETH/A: C15.1, TR1.15 (C_TX); also elsewhere on the board
/ETH/ACT_LED: R27.1, U6.27 (ACTLED)
/ETH/B: C12.1, TR1.10 (C_RX); also elsewhere on the board
/ETH/C: C11.1, J2.4, J2.5; also elsewhere on the board
/ETH/CLK: U6.33 (SCLK); also elsewhere on the board
/ETH/D: C10.1, J2.7, J2.8; also elsewhere on the board
/ETH/ETH_GND: C13.2, C14.1, J2.SH
/ETH/EXRES1: R28.2, U6.10 (EXRES1)
/ETH/INT: U6.36 (~INT); also elsewhere on the board
/ETH/MISO: U6.34 (MISO); also elsewhere on the board
/ETH/MOSI: U6.35 (MOSI); also elsewhere on the board
/ETH/PHY_RXC_N: C18.2, R25.2, R31.1
/ETH/PHY_RXC_P: C17.2, R24.2, R32.1
/ETH/PHY_RXM_N: C18.1, TR1.8 (RD-)
/ETH/PHY_RXM_P: C17.1, TR1.6 (RD+)
/ETH/PHY_RX_N: R31.2, U6.5 (RXN)
/ETH/PHY_RX_P: R32.2, U6.6 (RXP)
/ETH/PHY_TXM_N: R23.1, R29.1, TR1.3 (TD-)
/ETH/PHY_TXM_P: R22.1, R30.1, TR1.1 (TD+)
/ETH/PHY_TX_N: R29.2, U6.1 (TXN)
/ETH/PHY_TX_P: R30.2, U6.2 (TXP)
/ETH/RST: U6.37 (~RST); also elsewhere on the board
/ETH/SPD_LED: R26.1, U6.25 (LINKLED)
/ETH/TERM_COM: C13.1, R18.1, R19.1, R20.1, R21.1
/ETH/TOCAP: C24.1, U6.20 (TOCAP)
/ETH/XI: C32.1, R33.2, U6.30 (XI/CLKIN), Y1.3
/ETH/XO: C31.1, R33.1, U6.31 (XO), Y1.1
GND: C14.2, C16.2, C19.2, C20.2, C21.2, C22.2, C23.2, C24.2, C25.2, C26.2, C27.2, C28.2, C29.2, C30.2, C31.2, C32.2, D6.1 (K), D7.1 (K), R28.1, U6.3 (AGND), U6.9 (AGND), U6.14 (AGND), U6.16 (AGND), U6.19 (AGND), U6.29 (GND), U6.32 (~SCS), U6.48 (AGND), Y1.2, Y1.4; also elsewhere on the board
unnamed: C10.2, R18.2
unnamed: C11.2, R19.2
unnamed: C12.2, R20.2
unnamed: C15.2, R21.2
unnamed: C19.1, R24.1, R25.1
unnamed: D6.2 (A), R26.2
unnamed: D7.2 (A), R27.2
unnamed: J2.1, TR1.16 (TX+)
unnamed: J2.2, TR1.14 (TX-)
unnamed: J2.3, TR1.11 (RX+)
unnamed: J2.6, TR1.9 (RX-)

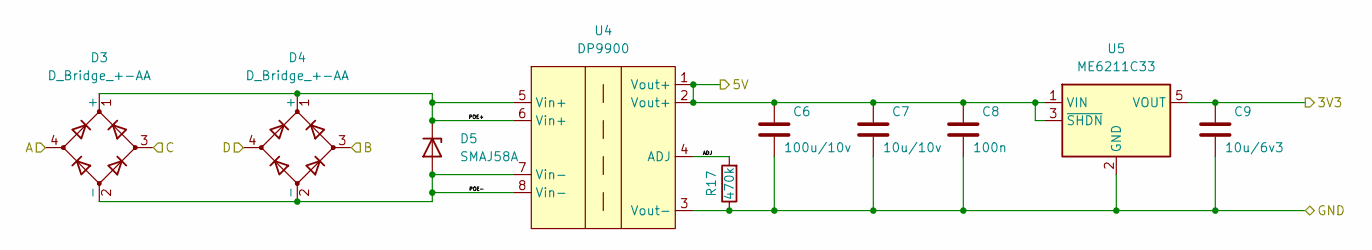
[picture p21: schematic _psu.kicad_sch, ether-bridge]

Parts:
C6: 100u/10v; C_1206_3216Metric_Pad1.33x1.80mm_HandSolder; jlc-part-type E+
C7: 10u/10v; C_0603_1608Metric_Pad1.08x0.95mm_HandSolder; jlc-part-type B+
C8: 100n; C_0402_1005Metric_Pad0.74x0.62mm_HandSolder; jlc-part-type B+
C9: 10u/6v3; C_0402_1005Metric_Pad0.74x0.62mm_HandSolder; jlc-part-type B+
D3, D4: D_Bridge_+-AA; Diode_Bridge_Diotec_MicroDil_3.0x3.0x1.8mm; jlc-part-type E+
D5: SMAJ58A; D_SMA; jlc-part-type E+
R17: 470k; R_0402_1005Metric_Pad0.72x0.64mm_HandSolder; jlc-part-type ER+
U4: DP9900; PSU_DP9900LP; jlc-part-type E+
U5: ME6211C33; SOT-23-5; jlc-part-type E+

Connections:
3V3: C9.1, U5.5 (VOUT); also elsewhere on the board
5V: C6.1, C7.1, C8.1, U4.1 (Vout+), U4.2 (Vout+), U5.1 (VIN), U5.3 (~SHDN); also elsewhere on the board
/ETH/A: D3.4; also elsewhere on the board
/ETH/B: D4.3; also elsewhere on the board
/ETH/C: D3.3; also elsewhere on the board
/ETH/D: D4.4; also elsewhere on the board
/PSU/ADJ: R17.2, U4.4 (ADJ)
/PSU/POE+: D3.1 (+), D4.1 (+), D5.1 (K), U4.5 (Vin+), U4.6 (Vin+)
/PSU/POE-: D3.2 (-), D4.2 (-), D5.2 (A), U4.7 (Vin-), U4.8 (Vin-)
GND: C6.2, C7.2, C8.2, C9.2, R17.1, U4.3 (Vout-), U5.2 (GND); also elsewhere on the board

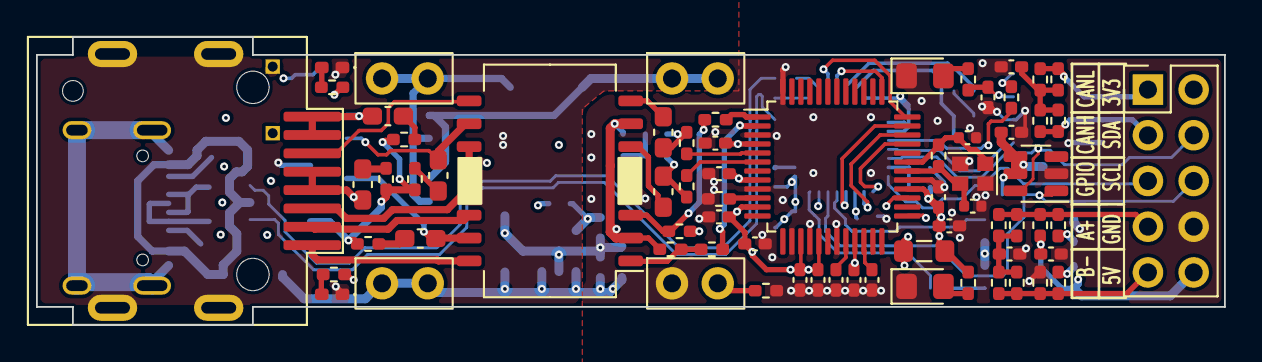
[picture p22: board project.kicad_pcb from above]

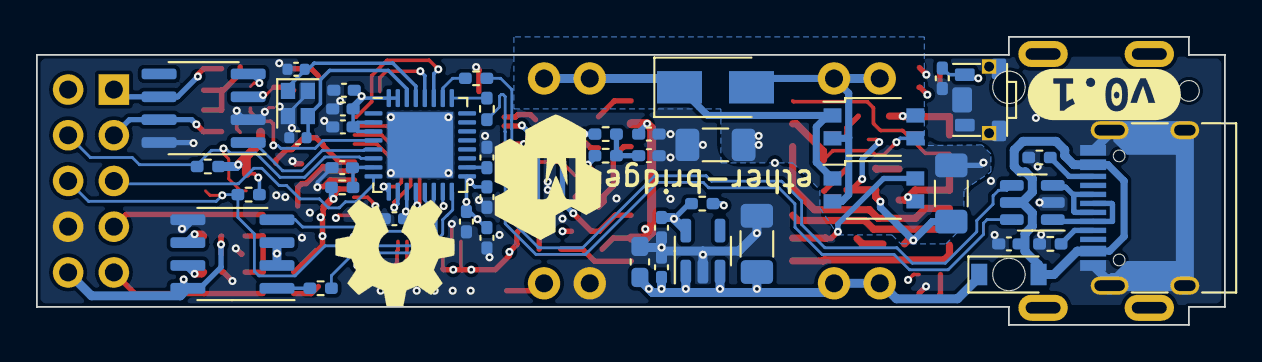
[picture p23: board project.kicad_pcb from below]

Board: 6 copper layers, 66.0 x 16.0 mm, 113 parts (47 on the bottom side), 79 nets.

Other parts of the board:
kibuzzard-6862F65F: G***; kibuzzard-6862F65F
